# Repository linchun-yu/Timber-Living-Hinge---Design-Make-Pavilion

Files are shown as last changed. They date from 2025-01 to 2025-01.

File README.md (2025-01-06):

## Introduction

Based on research into the relationship between cutting patterns and bending angles, parametric methods can be used to reverse-engineer the density of cutting patterns required for specific bending angles. This enables the design of highly customizable components for constructing complex shapes on a large scale.

While designing small-scale structures, it is crucial to consider not only the relationship between wood bending and cutting patterns but also the machining limits of the equipment and the material utilization rate. Through continuous trial and error, adjustments are made iteratively to optimize the process.

This project involves diverse tasks spanning experimentation, derivation, digital design, manufacturing, and geometric optimization. The research is planned to last approximately one year. The primary goal for this semester is to complete a full cycle of the design-to-manufacturing workflow, testing the physical and geometric limits of various material parameters and establishing the necessary tools for each step. In the following semester, the manufacturing experiences will be fed back into the initial design to refine both the overall form and localized details.

#### sample
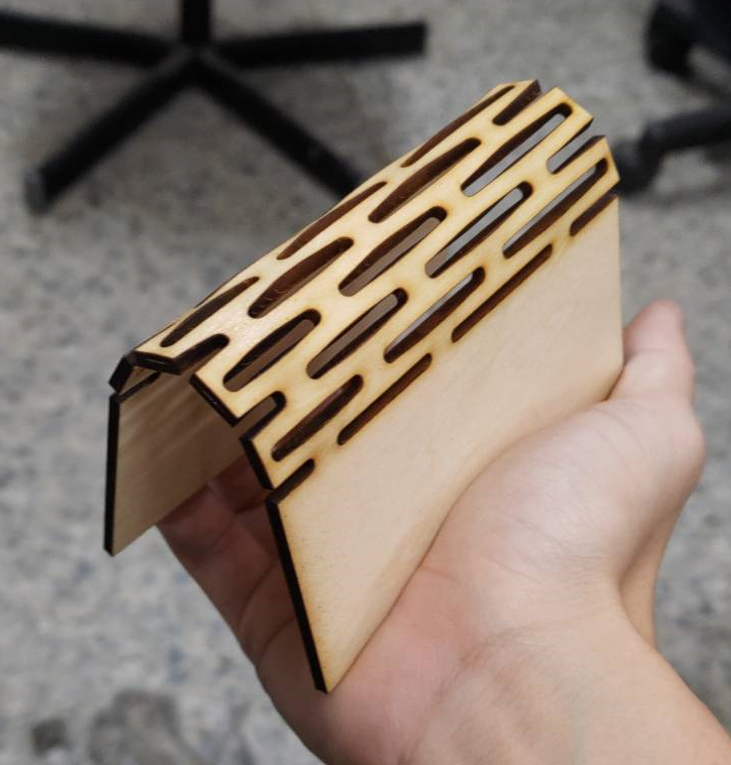
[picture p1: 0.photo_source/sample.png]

#### stage result
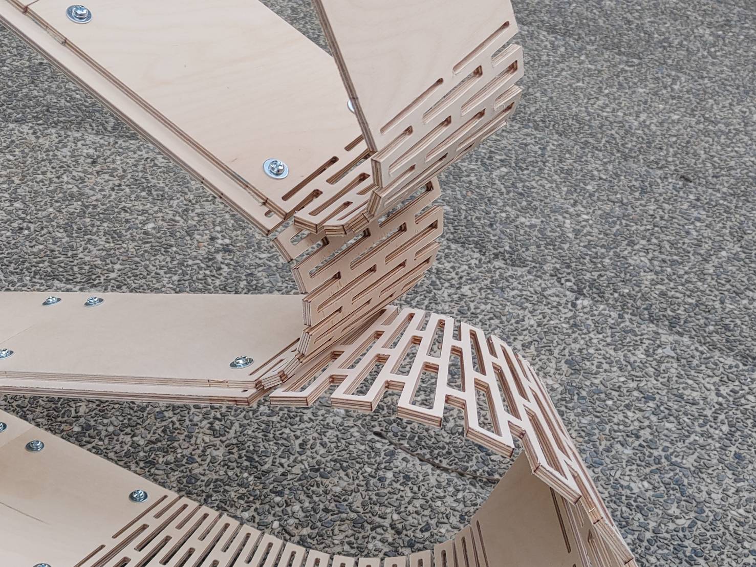
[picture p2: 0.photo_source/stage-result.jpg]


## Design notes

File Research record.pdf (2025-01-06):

## Timber Living Hinge – Design-Make Pavilion

Research Record of the Senior Year Design Studio for the first semester

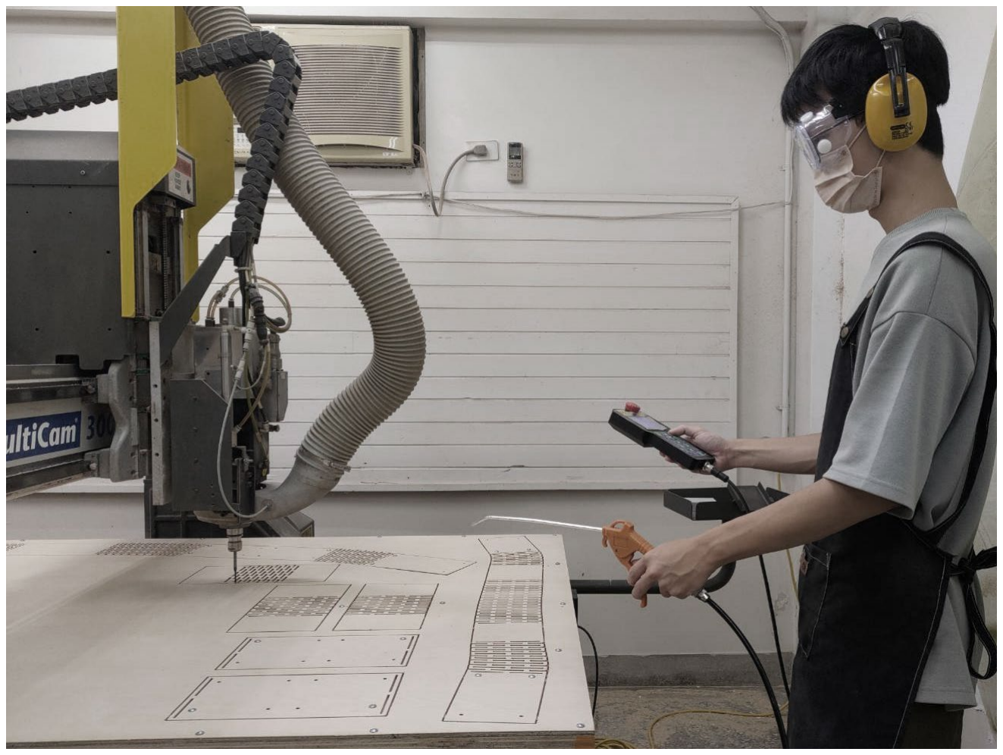
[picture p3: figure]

Author: Chun-Yu Lin

Mentor: Chia-Ching Yen

Department of Architecture, National Cheng Kung University

December 2024

### Contents

### List of Figures

### Chapter 1. Introduction

“Study the relationship between cutting patterns and bending angles, and use
this principle to design a small-scale pavilion” Based on research into the relationship between cutting patterns and bending angles, parametric methods can be used to reverse-engineer the density of cutting patterns required for specific bending angles. This enables the design of highly customizable components for constructing complex shapes on a large scale.
While designing small-scale structures, it is crucial to consider not only the relationship between wood bending and cutting patterns but also the machining limits of the equipment and the material utilization rate. Through continuous trial and error, adjustments are made iteratively to optimize the process.
This project involves diverse tasks spanning experimentation, derivation, digital design, manufacturing, and geometric optimization. The research is planned to last one year. The primary goal for this semester is to complete a full cycle of the design-make workflow, testing the physical and geometric limits of various material parameters and establishing the necessary tools for each step. In the following semester, the manufacturing experiences will be fed back into the initial design to refine both the overall form and localized details.

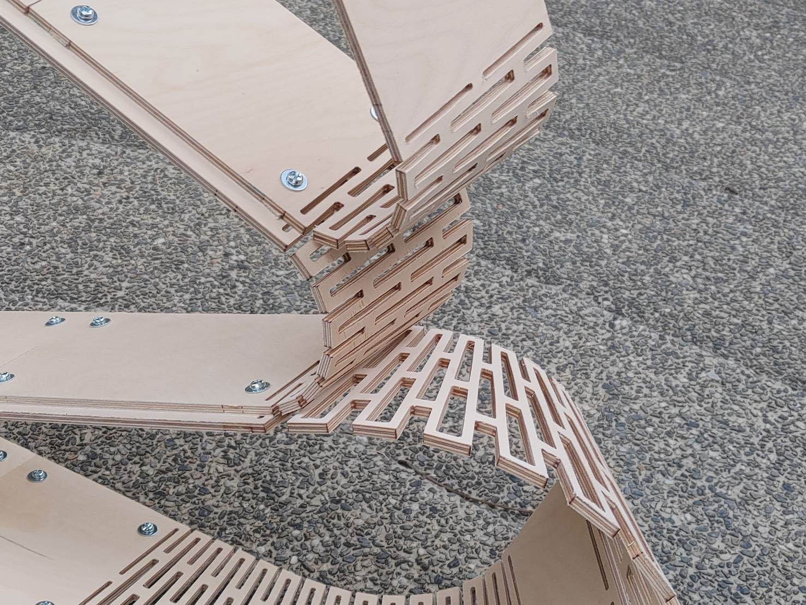
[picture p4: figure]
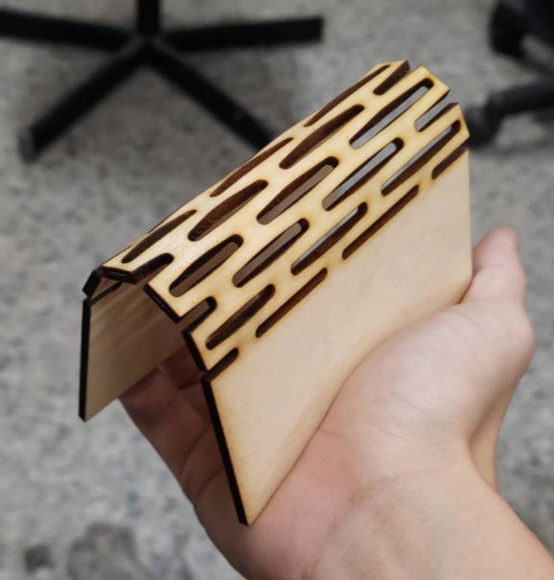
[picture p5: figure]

Figure 1 From start to stage feedback

### Chapter 2. Analysis of Physical Principle & Data Collection

Referring to others' analyses of this type of bending pattern, while many parameters can be controlled, the ones that significantly affect the bending angle are the length and cross-sectional area of the dark gray regions shown above.

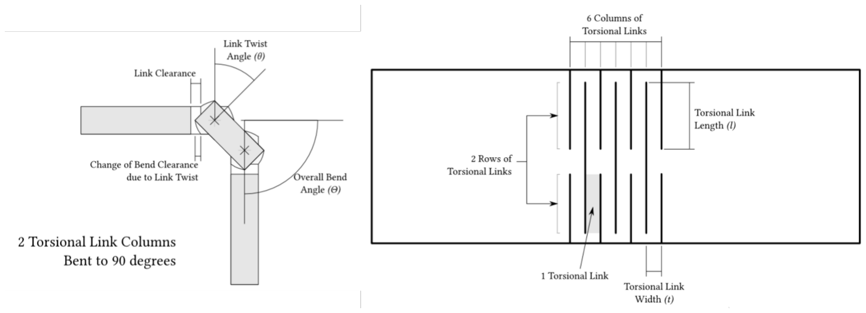
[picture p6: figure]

I designed a series of experiments to validate this idea by individually adjusting the width of the connections, length of the dark gray regions, number of raw, and cutting width. The specimens were suspended in fixtures, with weights added at the center to induce bending. A camera facing the observation plane was set up to record the results.

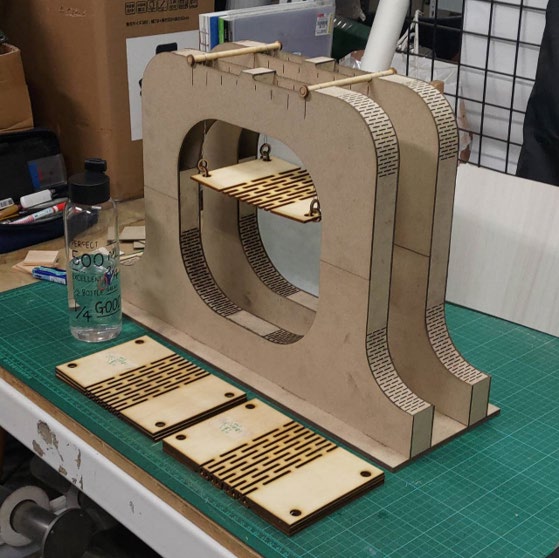
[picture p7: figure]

Figure 3 Bending angle observation tool

Figure 2 Analysis of living hinge pattern Source: https://marksabino.com/defproc/blog/2012/minimum-bend-radius/

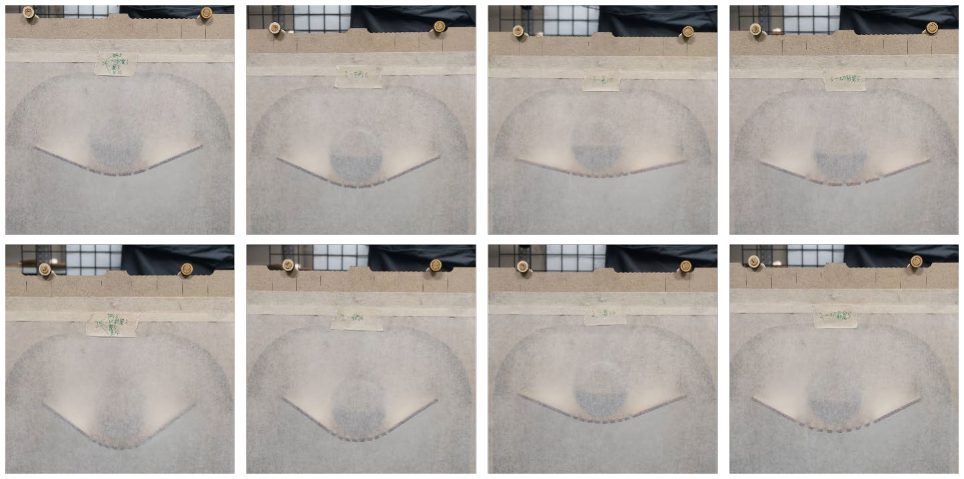
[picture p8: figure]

Figure 4 Photos of bending result with different parameters of the pattern
After verifying and analyzing the experimental photos, the following conclusions can be drawn:
- The bending angle is determined by the twisting of the dark gray areas (torsional links).
- The number of rows is related to the force required for bending but is unrelated to the achievable bending angle.
- The cutting width (W’cut) does not directly influence the bending behavior once the space required for twisting is satisfied.
- The pattern width (W) affects the bending radius but does not influence the bending angle. Therefore, in subsequent reverse-engineering processes, the focus should be on controlling the length and width of the torsional links, and other parameters can automatically adjust based on material properties and the required edge length.

Additionally, assuming the twisting occurs around the material's central axis and the patterns are equidistant, the bending result can be simplified into a mesh bevel. This simplification aids in visualizing and simulating bending outcomes. The achievable bending angle is related to the torsional links' cross-section and length (L). Future tests on bending capacity could involve designing experiments to measure the "twisting angle per unit length" for different cross-sections.

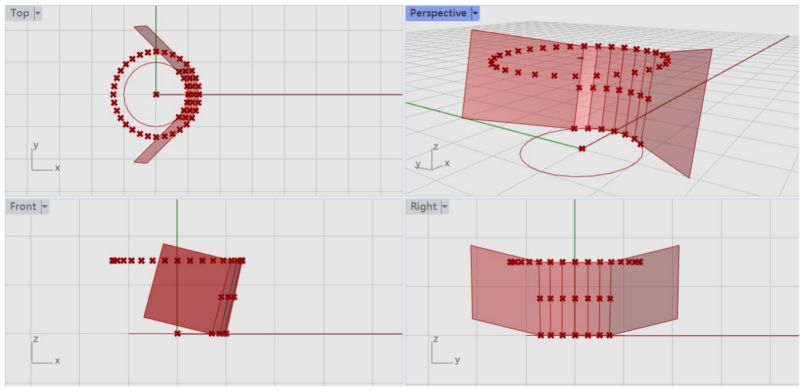
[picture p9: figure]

Figure 5 Simplified bending result

### Chapter 3. Form Design Concept

A single unit is formed by a triangle that encloses a circle, and its length can be adjusted according to the available raw material. For example, the CNC machine at National Chang Kung University has a cutting range of 2440mm by 1220mm, so the longest unit perimeter cannot exceed 240cm. In addition to controlling the result of the assembly by the flattened shape, and combining the previous research on the relationship between the pattern and strength, the bending angle of the shape affects the pattern density. By adjusting the strength at each bending point during assembly, the deformation of the shape can be controlled. Compared to laying out excessive cutting patterns, this method ensures that the strength is not significantly weakened.

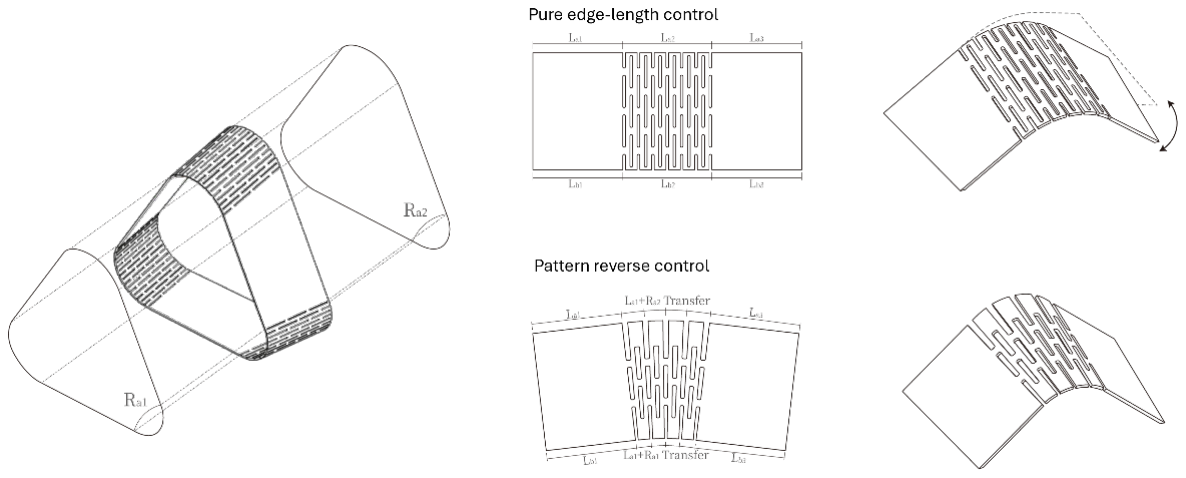
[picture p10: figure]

Figure 6 Comparison of two pattern-laying methods
The site is currently chosen to be the open space between the bicycle parking lots of Guangfu Building I and Guangfu Building II. The goal is to create a structure that extends outward and provides shade, offering a space for students who usually dine at the Guangfu student cafeteria to come here and have a picnic.

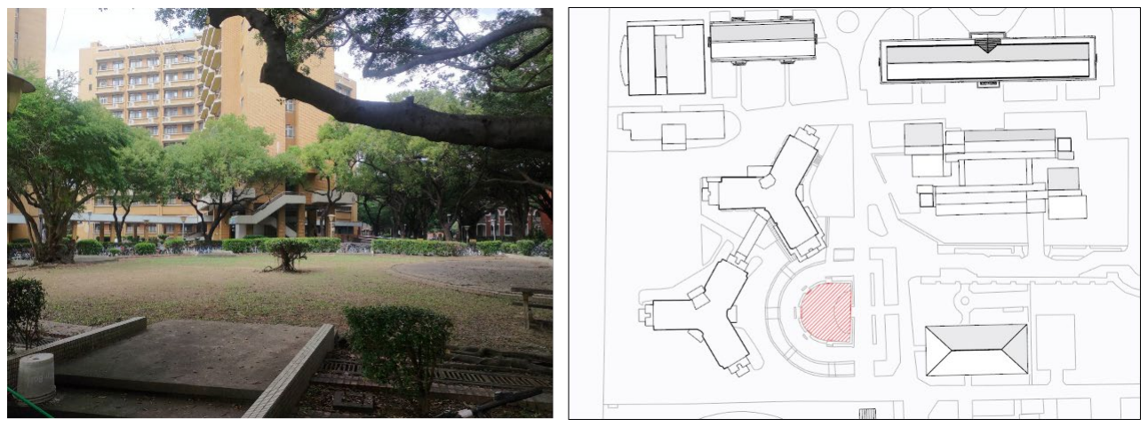
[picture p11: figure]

Figure 7 Site photo and plan

The upper sections of the three arches arranged in a circular layout are pushed outward and enlarged to provide shading. Physical simulations then determine the connecting surfaces between them, pulling the three curved surfaces inward to achieve balance. Finally, the designed patterns are mapped onto the surfaces and refined, using a single connection system to integrate multiple surfaces, thereby forming a complex topological relationship.

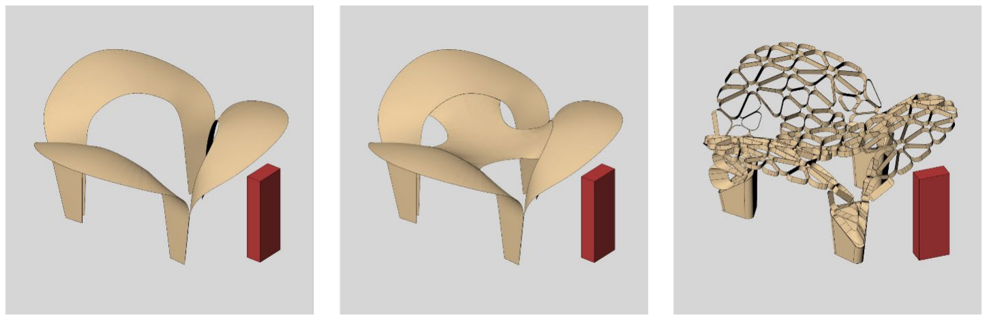
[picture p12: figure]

Figure 8 Design Evaluation

### Chapter 4. Background Technique

After finalizing the overall form, the desired distribution pattern is drawn within a planar simulation diagram. The inflection points of the pattern are converted into UV coordinates labeled (0~1, 0~1), which are then mapped onto the three-dimensional surface. By combining and trimming, multiple surfaces are integrated to form a complex topology.

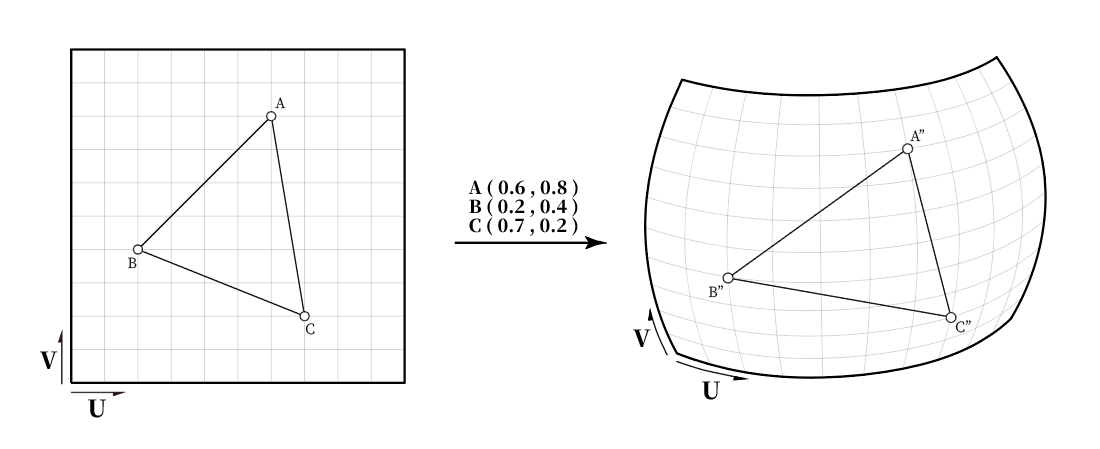
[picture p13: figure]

Figure 9 2D pattern to 3D pattern on surfaces
When a planar pattern is extruded to add thickness in the direction outside the surface, if "points" are used as the main body for normal movement, most surfaces, except for spheres, will make "four-point surfaces." This is because the normal of a sphere points to the center of the sphere, allowing it to form a plane with three points. However, it is difficult for other curved surfaces to have exactly four points in the same plane. Therefore, an alternative method needs to be found.

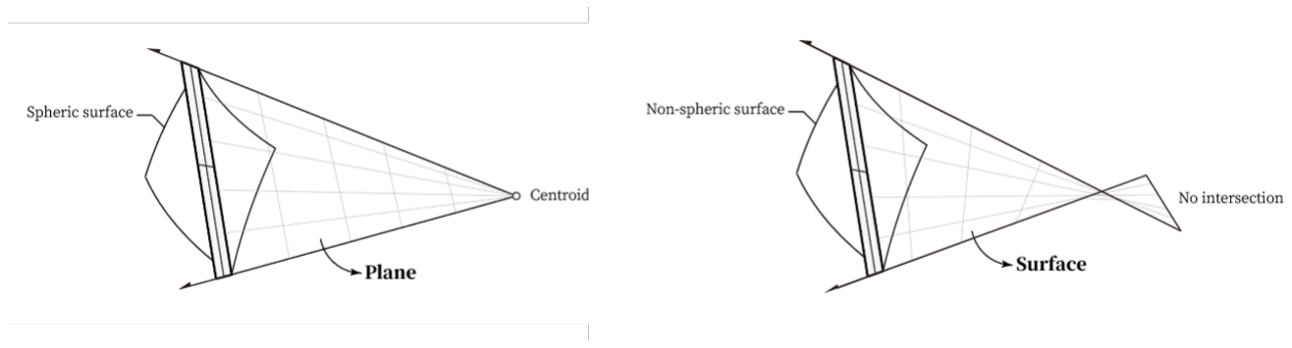
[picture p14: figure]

Figure 10 Analysis of out-of-plane Extrusion

Currently, the method uses the normal extrusion at the midpoint of "lines." The "intersection line" of two adjacent extruded planes serves as their boundary. This allows for the reverse calculation of the direction points move (which may not be exactly aligned with the normal direction). Points at the same position in different triangles will generate different "intersection lines," so curved corners are even more necessary to prevent collisions.

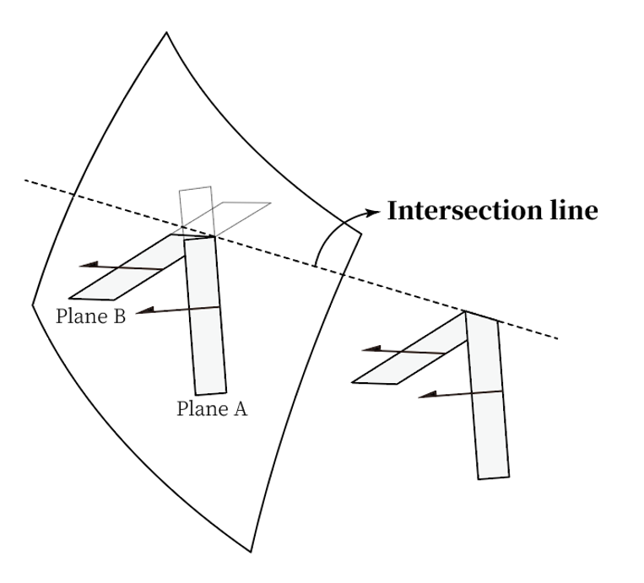
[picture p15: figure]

Figure 11 3D pattern to entity

### Chapter 5. Detailed Adjustment

To reduce the overall weight, a thicker 6mm birch plywood is used at the contact points with the ground, while the remaining majority of the material is only 4mm thick. In addition, a gradual width transition is set, reducing from 15cm at the bottom to 9cm at the top. As mentioned earlier, the bending ability is proportional to the length of the torsional links, so the width cannot be too narrow.
In the last section of the Background Technique chapter, I mentioned that the extruded surfaces may collide. This issue becomes more pronounced in areas with significant curvature changes. Additionally, since turning requires sufficient distance to form, the sharp angles should be smoothed into rounded corners, and this adjustment should vary according to the curvature of the area. The lengths of both sides of this angle also need to be taken into consideration.

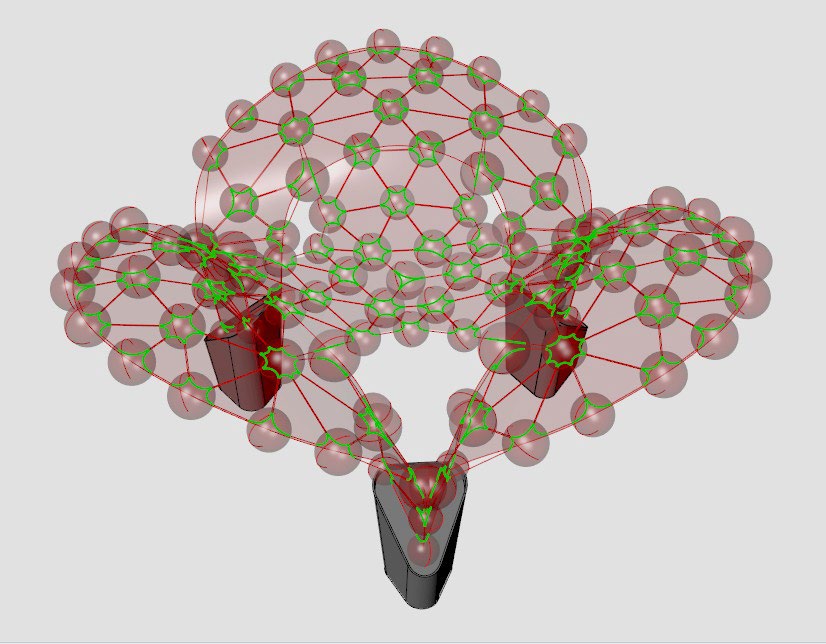
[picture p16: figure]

Figure 12 Control of the bending Region

### Chapter 6. Manufacturing & Construction

After multiple operations on the school's CNC machine to cut and bend the patterns, the following stable parameters have been established:
1. The width of the torsional links should be greater than 5mm, otherwise, the surface wood is prone to being torn apart.
2. The width of the cutting gap should be 2mm larger than the diameter of the flat end mill (currently 3mm diameter), or rounded corners should be set at entry points of sharp turns.
3. The cutting depth for each pass should be set to 2-3mm.

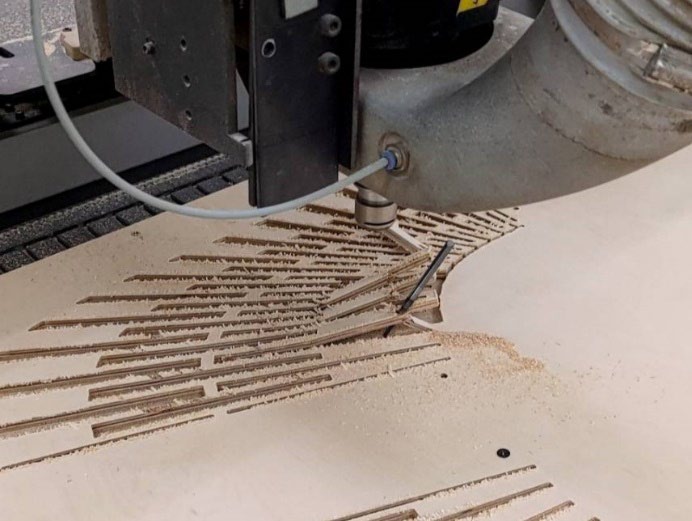
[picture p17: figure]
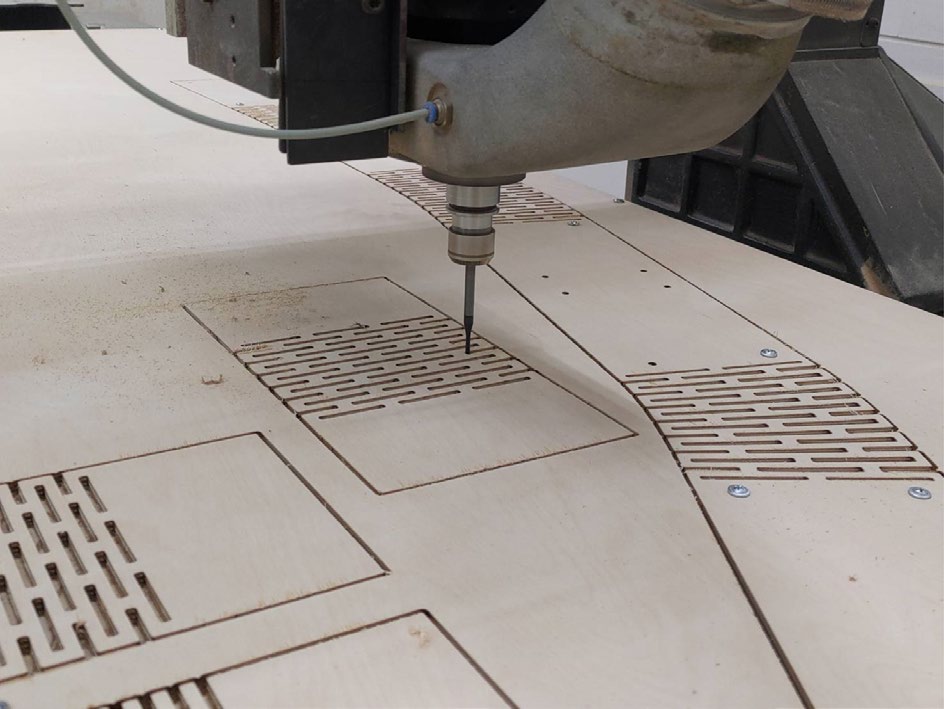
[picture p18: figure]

Based on the currently specified board thickness, the cost estimation for the upper part, excluding the base, requires 6 sheets of 6mm birch plywood and 15 sheets of 4 mm, with a total cost of approximately 25,000 NTD (800 USD).

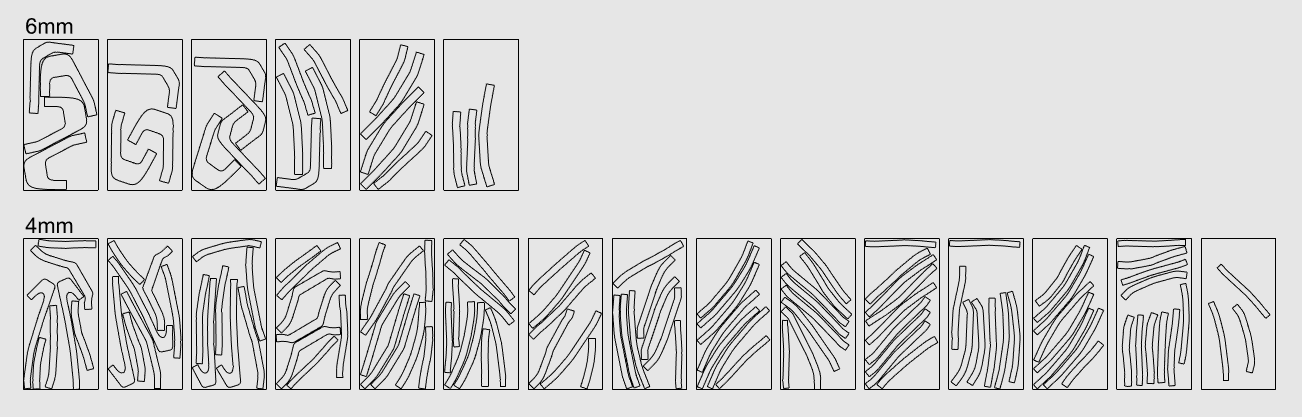
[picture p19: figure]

Figure 14 Material utilization and estimation

Figure 13 Photos of CNC manufacturing process

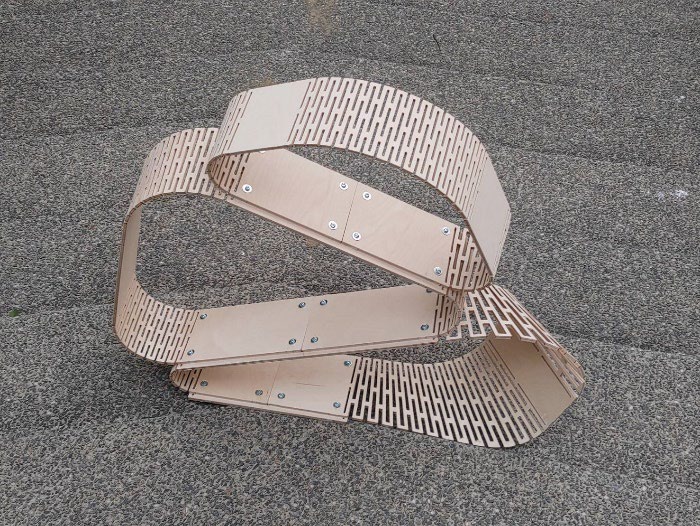
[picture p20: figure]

Figure 15 Full-scale test model photo 1

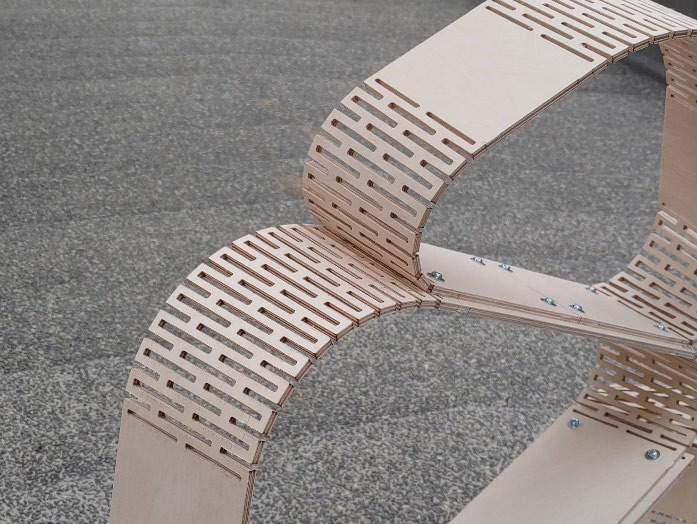
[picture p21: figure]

Figure 16 Full-scale test model photo 2

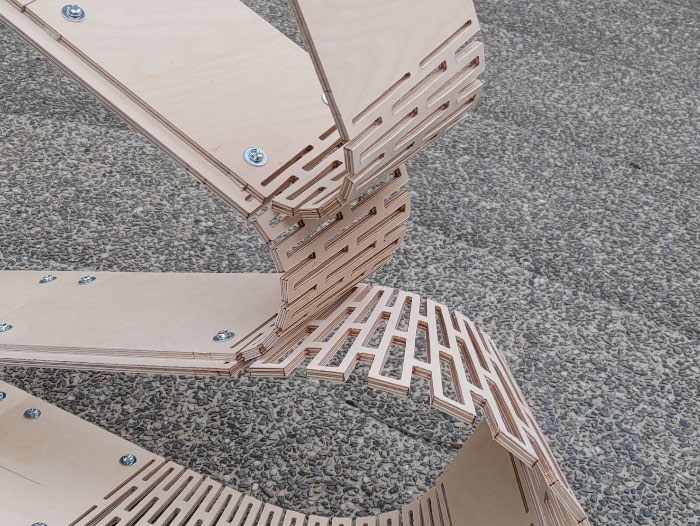
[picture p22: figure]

Figure 17 Full-scale test model photo 3

### Chapter 7. Stage Feedback and To-Do List

Next semester, the first goal is to conduct experiments to determine the "twisting angle per unit length" for different cross-sections. When generating the pattern, divide the required angle by this value to obtain the necessary twist length. Then, in accordance with the appropriate specifications of the manufacturing machine mentioned in Chapter 6, generate the cutting pattern, thereby achieving the reverse engineering of Living Hinge.

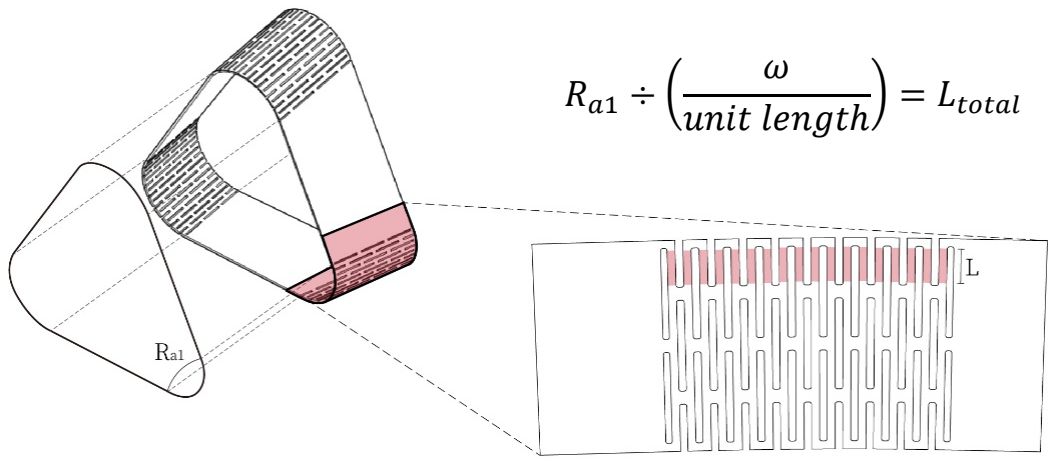
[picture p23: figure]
RRaa1 ÷  ωω uuuuuuuu llll ll ℎ;  = LLtttttt tt

Figure 18 Reverse engineering of Living Hinge.
It was observed that the bending area continues to deform due to pressure, gradually expanding outward. Therefore, the design needs to be further constrained at the edges.

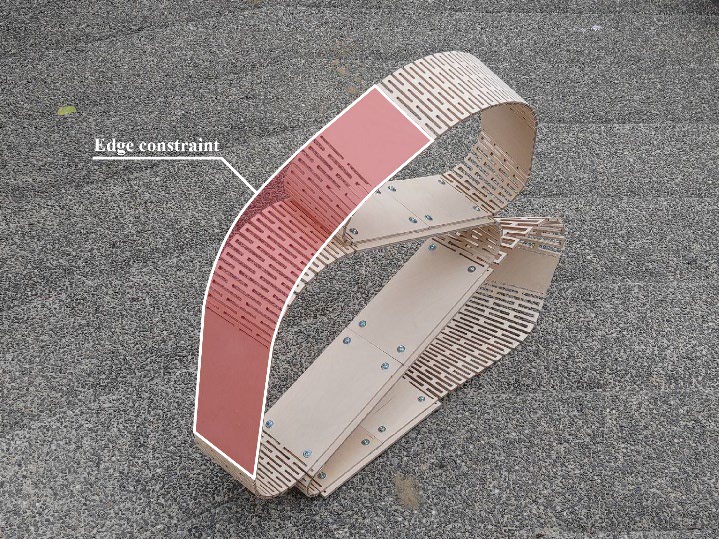
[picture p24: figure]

Figure 19 Edge constraint
Connect the analysis results of material utilization with the initial design to establish a method for optimizing utilization. It is also necessary to test structural stability and review the design's shape based on multiple existing factors.

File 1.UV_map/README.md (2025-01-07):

## UV map
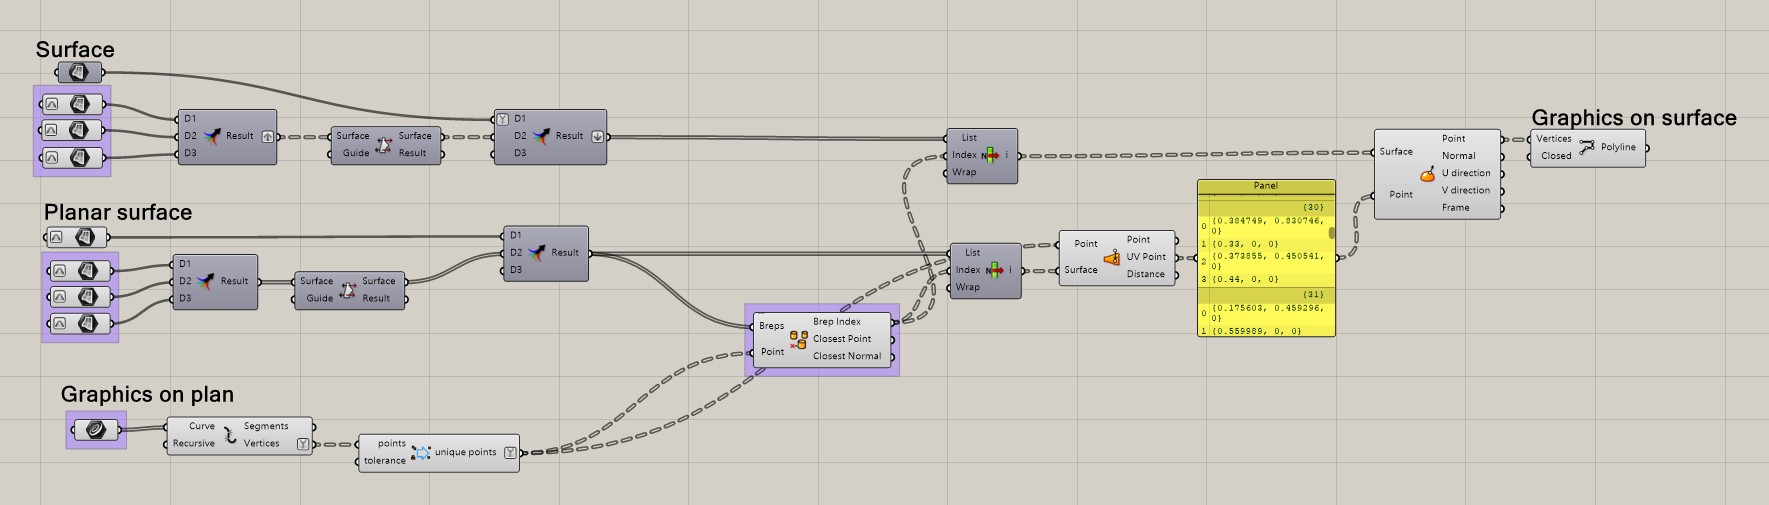
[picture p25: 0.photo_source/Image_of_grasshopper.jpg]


Mapping multiple planar shapes onto a surface in one time go involves four main steps.
1. Prepare the planes and the surface to be used and arrange them in a corresponding list. 
2. Draw the planar shapes that need to be mapped.
3. Determine which plane each node of the shapes belongs to.
4. Map the points to their corresponding positions on the surface.

Since the first two steps are preparatory and relatively simple, I will focus on explaining the last two steps.

#### Which surface
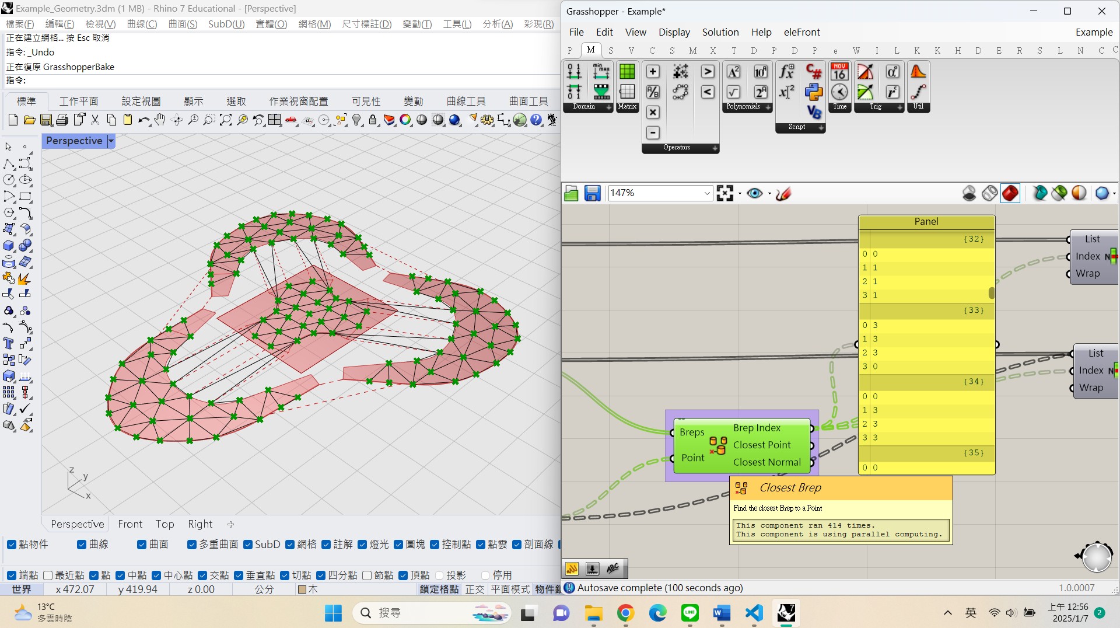
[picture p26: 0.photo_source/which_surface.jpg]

First, convert the planar shapes into points, and then use the "Closest Brep" component to find the nearest Brep. When there is no overlap between planes, the closest Brep will inevitably be the one that encloses the point. From this, we can determine which plane or surface the point belongs to and subsequently map it to the corresponding numbered 3D surface.

#### Map

The detailed process of UV mapping is as follows. First, use the "Surface Closest Point" component to obtain the UV coordinates of a point on the planar shape. Next, apply the "Evaluate Surface" component, which analyzes the parameters of the UV point on the surface. This component is particularly useful for mapping the UV points from the plane to the corresponding positions on the surface.

Once these steps are completed, connect the points using the "Polyline" component to form the desired shape on the surface. The final result is as follows.

<<<<<<< HEAD:1.UV_map/README.md

=======

>>>>>>> 832ee87f3b8a1bc97a25c948d2a0db227e31946b:1.UV_map/0.README.md

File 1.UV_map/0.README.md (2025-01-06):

## UV map

Mapping multiple planar shapes onto a surface in one time go involves four main steps.
1. Prepare the planes and the surface to be used and arrange them in a corresponding list. 
2. Draw the planar shapes that need to be mapped.
3. Determine which plane each node of the shapes belongs to.
4. Map the points to their corresponding positions on the surface.

Since the first two steps are preparatory and relatively simple, I will focus on explaining the last two steps.

#### Which surface

First, convert the planar shapes into points, and then use the "Closest Brep" component to find the nearest Brep. When there is no overlap between planes, the closest Brep will inevitably be the one that encloses the point. From this, we can determine which plane or surface the point belongs to and subsequently map it to the corresponding numbered 3D surface.

#### Map

The detailed process of UV mapping is as follows. First, use the "Surface Closest Point" component to obtain the UV coordinates of a point on the planar shape. Next, apply the "Evaluate Surface" component, which analyzes the parameters of the UV point on the surface. This component is particularly useful for mapping the UV points from the plane to the corresponding positions on the surface.

Once these steps are completed, connect the points using the "Polyline" component to form the desired shape on the surface. The final result is as follows.



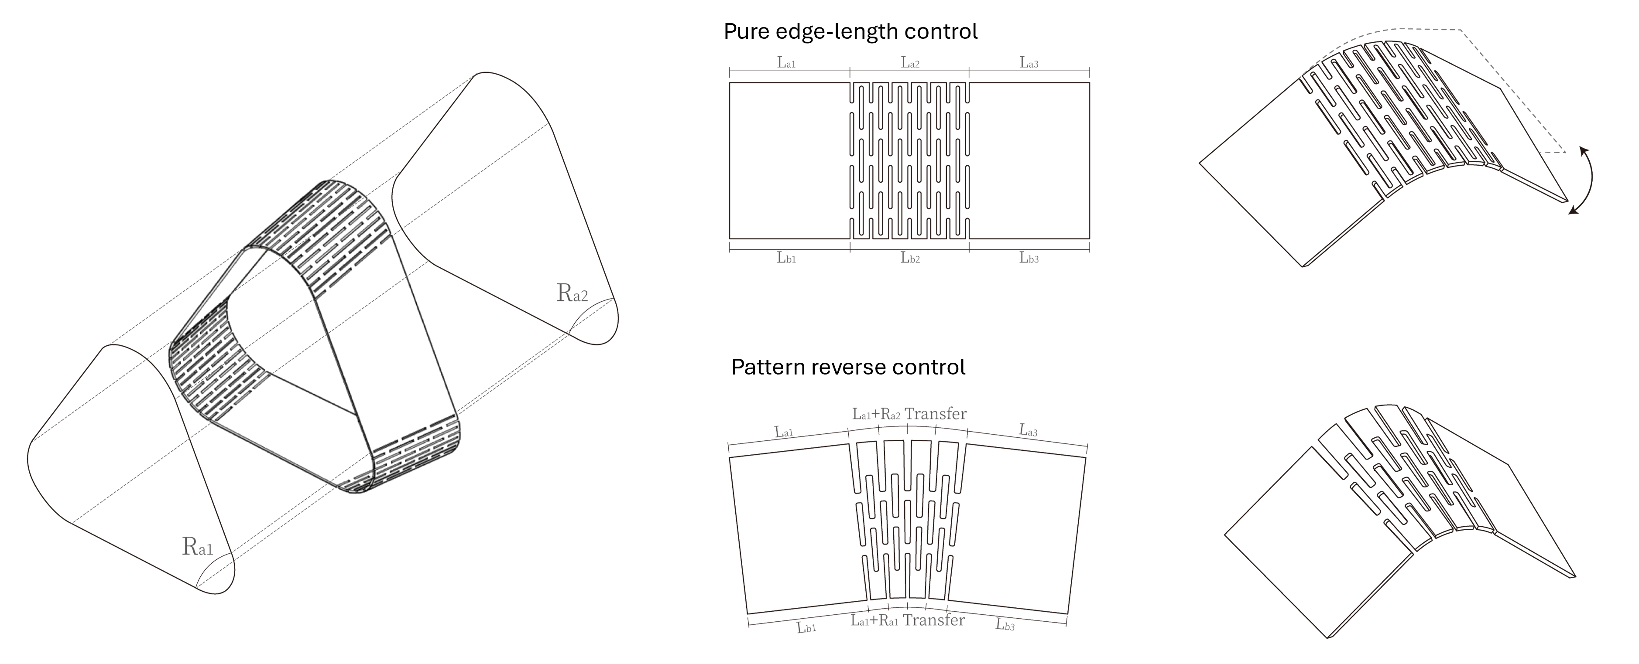
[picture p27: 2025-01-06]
0.photo_source/concept.png

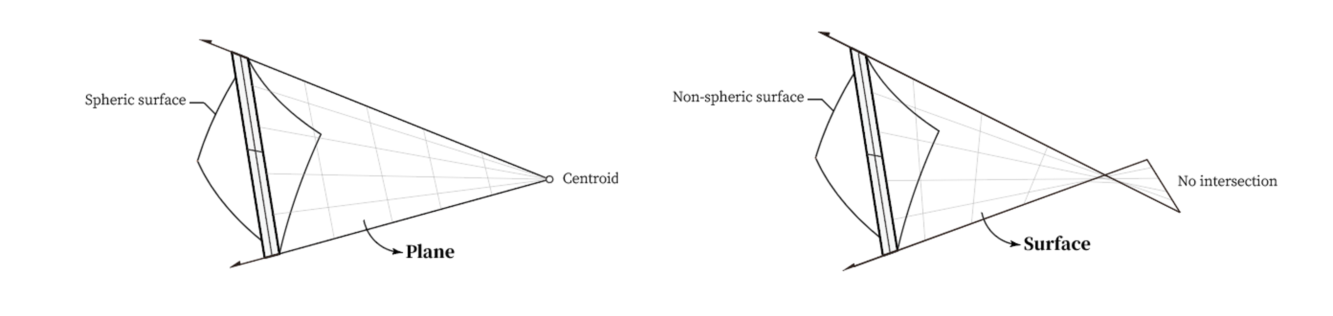
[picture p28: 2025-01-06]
0.photo_source/technique2.png

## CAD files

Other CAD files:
1.UV_map/Example_Geometry.3dm
